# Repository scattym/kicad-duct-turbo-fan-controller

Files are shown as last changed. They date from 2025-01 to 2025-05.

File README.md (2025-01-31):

# kicad-duct-turbo-fan-controller
Wifi enabled fan controller projects for the duct turbo (ducturbo), terrabloom and ac infinity fans

Simple project marrying up 3 premade boards, the esp32 doit v2, a buck-boost board and a scd41 board.

Connects to the ducturbo 3.5mm to PWM control the fan speed.

Low side mosfet PWM chosen so that removal (or potentially failure) of the esp32 keeps the fan off.

Board will also work with the AC Infinity fans however there seems to be in internal 10k resistor on these fans, so changing R5 from 10K to 1K is needed to get the "off" voltage down to under 1 volt. With the following pins:

GND → GND

10V → VBUS

PWM → D+

TACH → D-

duct-turbo-fan-controller - original based of esp32 doit it board - done - tested

duct-turbo-fan-controller-v2 - moved to esp32-c3-wroom-02 - done - waiting testing

duct-turbo-fan-controller-v3 - add bme680 on board allow usb to power esp for programming - done - untested

duct-turbo-fan-controller-v4 - on board buck converter and on board scd41 - done - waiting testing

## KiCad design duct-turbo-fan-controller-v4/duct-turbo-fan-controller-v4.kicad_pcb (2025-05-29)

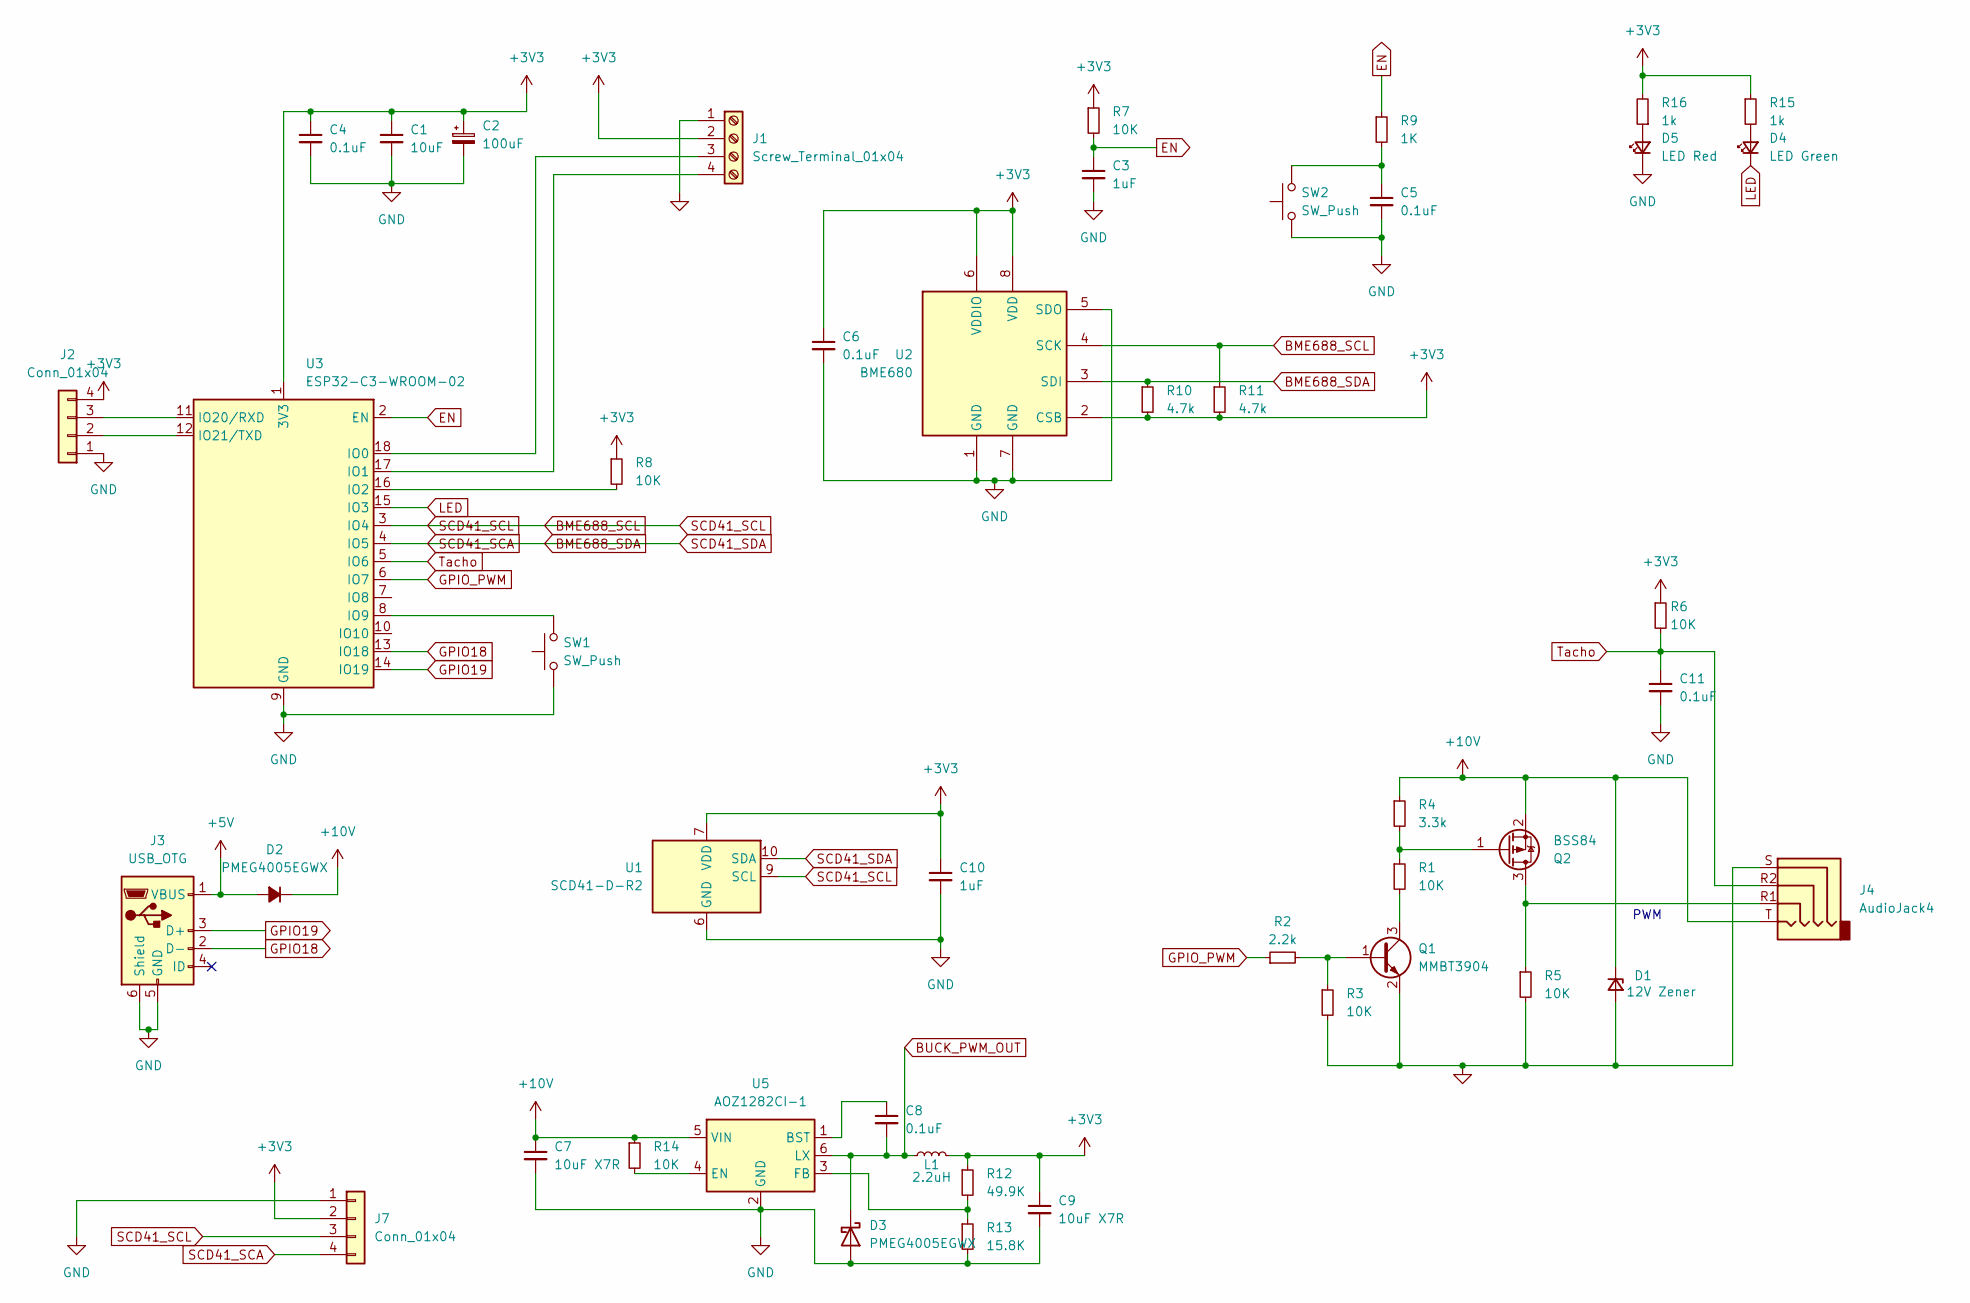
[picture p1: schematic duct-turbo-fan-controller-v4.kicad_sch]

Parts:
C1: 10uF; C_0805_2012Metric_Pad1.18x1.45mm_HandSolder
C2: 100uF; CP_EIA-3528-12_Kemet-T_Pad1.50x2.35mm_HandSolder
C3, C10: 1uF; C_0805_2012Metric_Pad1.18x1.45mm_HandSolder
C4, C5, C8: 0.1uF; C_0805_2012Metric_Pad1.18x1.45mm_HandSolder
C6, C11: 0.1uF; C_0603_1608Metric_Pad1.08x0.95mm_HandSolder
C7, C9: 10uF X7R; C_0805_2012Metric_Pad1.18x1.45mm_HandSolder
D1: 12V Zener; D_0805_2012Metric_Pad1.15x1.40mm_HandSolder
D2, D3: PMEG4005EGWX; D_SOD-123
D4: LED Green; LED_0603_1608Metric_Pad1.05x0.95mm_HandSolder
D5: LED Red; LED_0603_1608Metric_Pad1.05x0.95mm_HandSolder
J1: Screw_Terminal_01x04; TerminalBlock_Phoenix_MPT-0,5-4-2.54_1x04_P2.54mm_Horizontal
J2, J7: Conn_01x04; PinHeader_1x04_P2.54mm_Vertical
J3: USB_OTG; USB_Micro-B_Molex-105017-0001
J4: AudioJack4; Jack_3.5mm_KoreanHropartsElec_PJ-320D-4A_Horizontal
L1: 2.2uH; L_Bourns-SRN4018
Q1: MMBT3904; SOT-23
Q2: BSS84; SOT-23
R1, R3, R5, R7, R14: 10K; R_0805_2012Metric_Pad1.20x1.40mm_HandSolder
R2: 2.2k; R_0805_2012Metric_Pad1.20x1.40mm_HandSolder
R4: 3.3k; R_0805_2012Metric_Pad1.20x1.40mm_HandSolder
R6, R8: 10K; R_0603_1608Metric_Pad0.98x0.95mm_HandSolder
R9: 1K; R_0805_2012Metric_Pad1.20x1.40mm_HandSolder
R10, R11: 4.7k; R_0603_1608Metric_Pad0.98x0.95mm_HandSolder
R12: 49.9K; R_0805_2012Metric_Pad1.20x1.40mm_HandSolder
R13: 15.8K; R_0805_2012Metric_Pad1.20x1.40mm_HandSolder
R15, R16: 1k; R_0603_1608Metric_Pad0.98x0.95mm_HandSolder
SW1, SW2: SW_Push; SW_SPST_CK_RS282G05A3
U1: SCD41-D-R2; Sensirion_SCD4x-1EP_10.1x10.1mm_P1.25mm_EP4.8x4.8mm
U2: BME680; Bosch_LGA-8_3x3mm_P0.8mm_ClockwisePinNumbering
U3: ESP32-C3-WROOM-02
U5: AOZ1282CI-1; SOT-23-6

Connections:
+3V3: C1.1, C2.1, C4.1, C6.1, C9.1, C10.1, J1.2, J2.4, J7.2, L1.2, R6.1, R7.1, R8.1, R10.2, R11.2, R12.1, R15.1, R16.2, U1.7 (VDD), U1.19 (VDD), U2.2 (CSB), U2.6 (VDDIO), U2.8 (VDD), U3.1 (3V3)
+5V: D2.2 (A), J3.1 (VBUS)
+10V: C7.1, D1.1 (K), D2.1 (K), J4.T, Q2.2 (S), R4.1, R14.1, U5.5 (VIN)
BME688_SCL: J7.3, R11.1, U1.9 (SCL), U2.4 (SCK), U3.3 (IO4)
BME688_SDA: J7.4, R10.1, U1.10 (SDA), U2.3 (SDI), U3.4 (IO5)
BUCK_PWM_OUT: C8.2, D3.1 (K), L1.1, U5.6 (LX)
EN: C3.1, R7.2, R9.1, U3.2 (EN)
GND: C1.2, C2.2, C3.2, C4.2, C5.2, C6.2, C7.2, C9.2, C10.2, C11.2, D1.2 (A), D3.2 (A), D5.1 (K), J1.1, J2.1, J3.5 (GND), J3.6 (Shield), J4.S, J7.1, Q1.2 (E), R3.2, R5.2, R13.2, SW1.1, SW2.1, U1.6 (GND), U1.20 (GND), U1.21 (GND), U2.1 (GND), U2.5 (SDO), U2.7 (GND), U3.9 (GND), U3.19 (GND), U5.2 (GND)
GPIO18: J3.2 (D-), U3.13 (IO18)
GPIO19: J3.3 (D+), U3.14 (IO19)
GPIO_PWM: R2.1, U3.6 (IO7)
LED: D4.1 (K), U3.15 (IO3)
unnamed: C5.1, R9.2, SW2.2
unnamed: D4.2 (A), R15.2
unnamed: D5.2 (A), R16.1
unnamed: J1.3, U3.18 (IO0)
unnamed: J1.4, U3.17 (IO1)
unnamed: J2.2, U3.12 (IO21/TXD)
unnamed: J2.3, U3.11 (IO20/RXD)
unnamed: Q1.1 (B), R2.2, R3.1
unnamed: Q1.3 (C), R1.2
unnamed: J4.R1, Q2.3 (D), R5.1
unnamed: Q2.1 (G), R1.1, R4.2
unnamed: R8.2, U3.16 (IO2)
unnamed: SW1.2, U3.8 (IO9)
unnamed: C8.1, U5.1 (BST)
unnamed: R14.2, U5.4 (EN)
unnamed: R12.2, R13.1, U5.3 (FB)
Tacho: C11.1, J4.R2, R6.2, U3.5 (IO6)

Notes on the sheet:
PWM

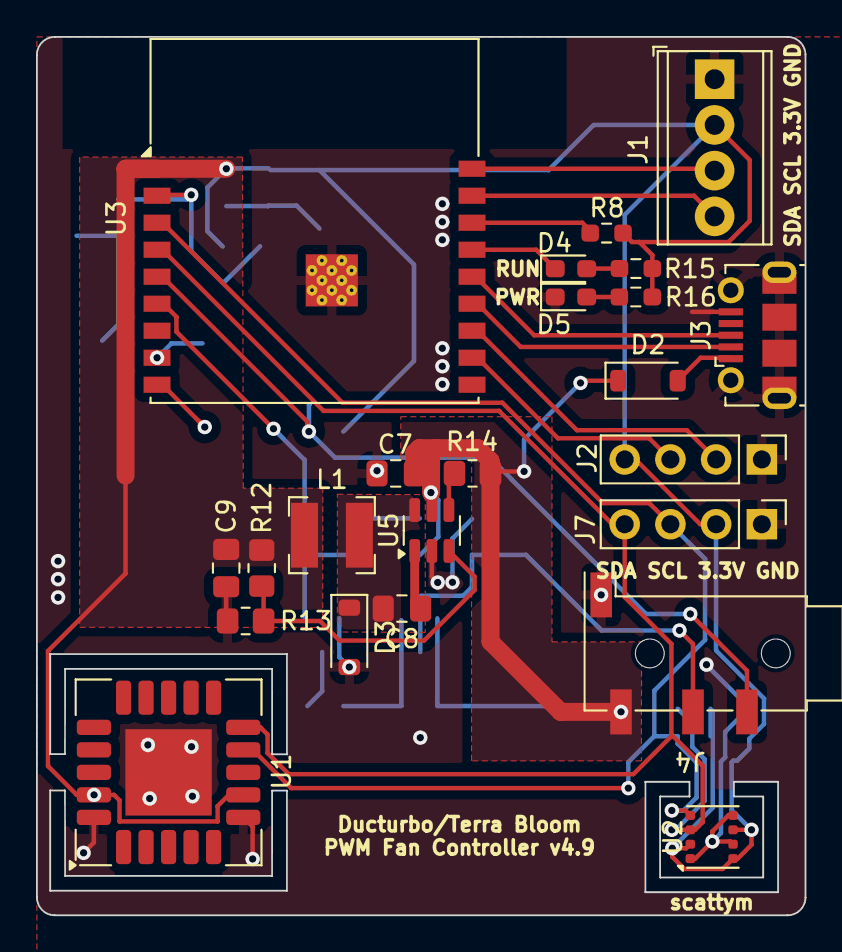
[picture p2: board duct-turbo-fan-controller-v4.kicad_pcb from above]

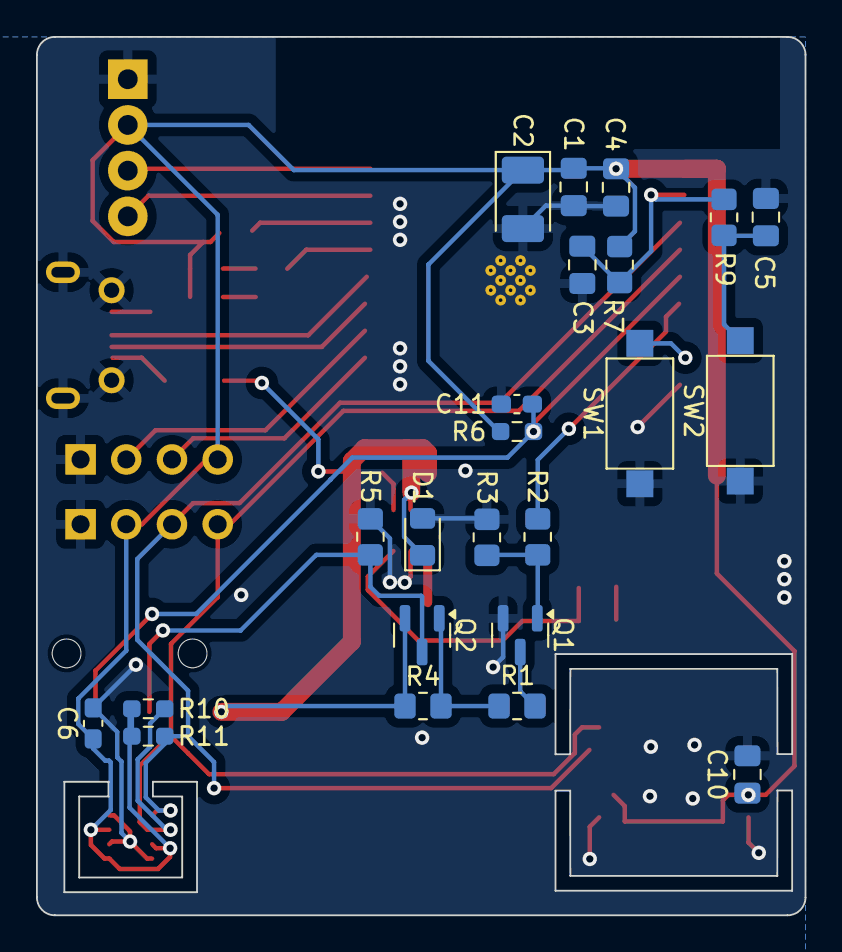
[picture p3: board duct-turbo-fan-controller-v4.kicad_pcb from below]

Board: 2 copper layers, 42.7 x 48.8 mm, 46 parts (23 on the bottom side), 29 nets.

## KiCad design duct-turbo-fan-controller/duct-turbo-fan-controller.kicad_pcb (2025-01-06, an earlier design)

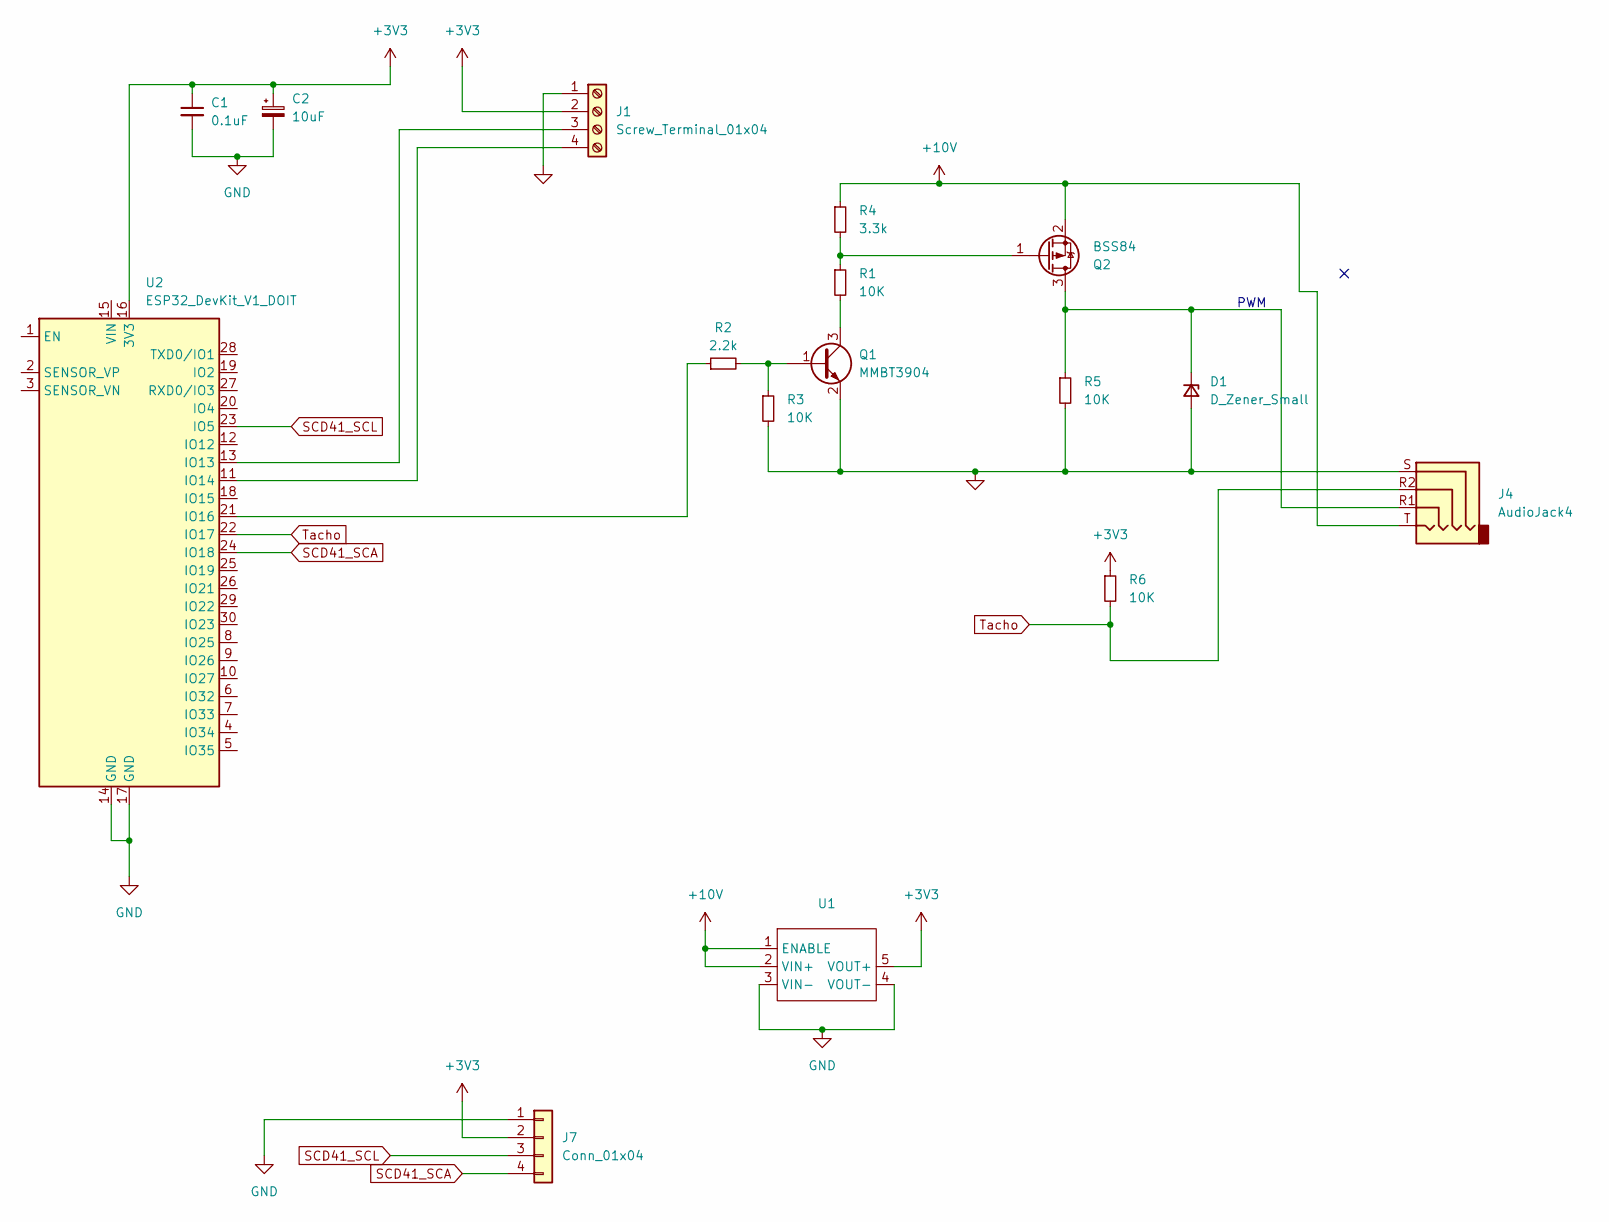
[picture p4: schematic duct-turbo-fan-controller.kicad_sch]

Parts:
C1: 0.1uF; C_0805_2012Metric_Pad1.18x1.45mm_HandSolder
C2: 10uF; CP_EIA-3528-12_Kemet-T_Pad1.50x2.35mm_HandSolder
D1: D_Zener_Small; D_0805_2012Metric_Pad1.15x1.40mm_HandSolder
J1: Screw_Terminal_01x04; TerminalBlock_Phoenix_MPT-0,5-4-2.54_1x04_P2.54mm_Horizontal
J4: AudioJack4; Jack_3.5mm_KoreanHropartsElec_PJ-320D-4A_Horizontal
J7: Conn_01x04; PinHeader_1x04_P2.54mm_Vertical
Q1: MMBT3904; SOT-23
Q2: BSS84; SOT-23
R1, R3, R5, R6: 10K; R_0805_2012Metric_Pad1.20x1.40mm_HandSolder
R2: 2.2k; R_0805_2012Metric_Pad1.20x1.40mm_HandSolder
R4: 3.3k; R_0805_2012Metric_Pad1.20x1.40mm_HandSolder
U1: Buck-Boost-Converter-Board-3.3V
U2: ESP32_DevKit_V1_DOIT; esp32_devkit_v1_doit

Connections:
+3V3: C1.1, C2.1, J1.2, J7.2, R6.1, U1.5 (VOUT+), U2.16 (3V3)
+10V: J4.T, Q2.2 (S), R4.1, U1.1 (ENABLE), U1.2 (VIN+)
GND: C1.2, C2.2, D1.2 (A), J1.1, J4.S, J7.1, Q1.2 (E), R3.2, R5.2, U1.3 (VIN-), U1.4 (VOUT-), U2.14 (GND), U2.17 (GND)
unnamed: D1.1 (K), J4.R1, Q2.3 (D), R5.1
unnamed: J1.3, U2.13 (IO13)
unnamed: J1.4, U2.11 (IO14)
unnamed: Q1.1 (B), R2.2, R3.1
unnamed: Q1.3 (C), R1.2
unnamed: Q2.1 (G), R1.1, R4.2
unnamed: R2.1, U2.21 (IO16)
SCD41_SCA: J7.4, U2.24 (IO18)
SCD41_SCL: J7.3, U2.23 (IO5)
Tacho: J4.R2, R6.2, U2.22 (IO17)

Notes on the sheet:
PWM

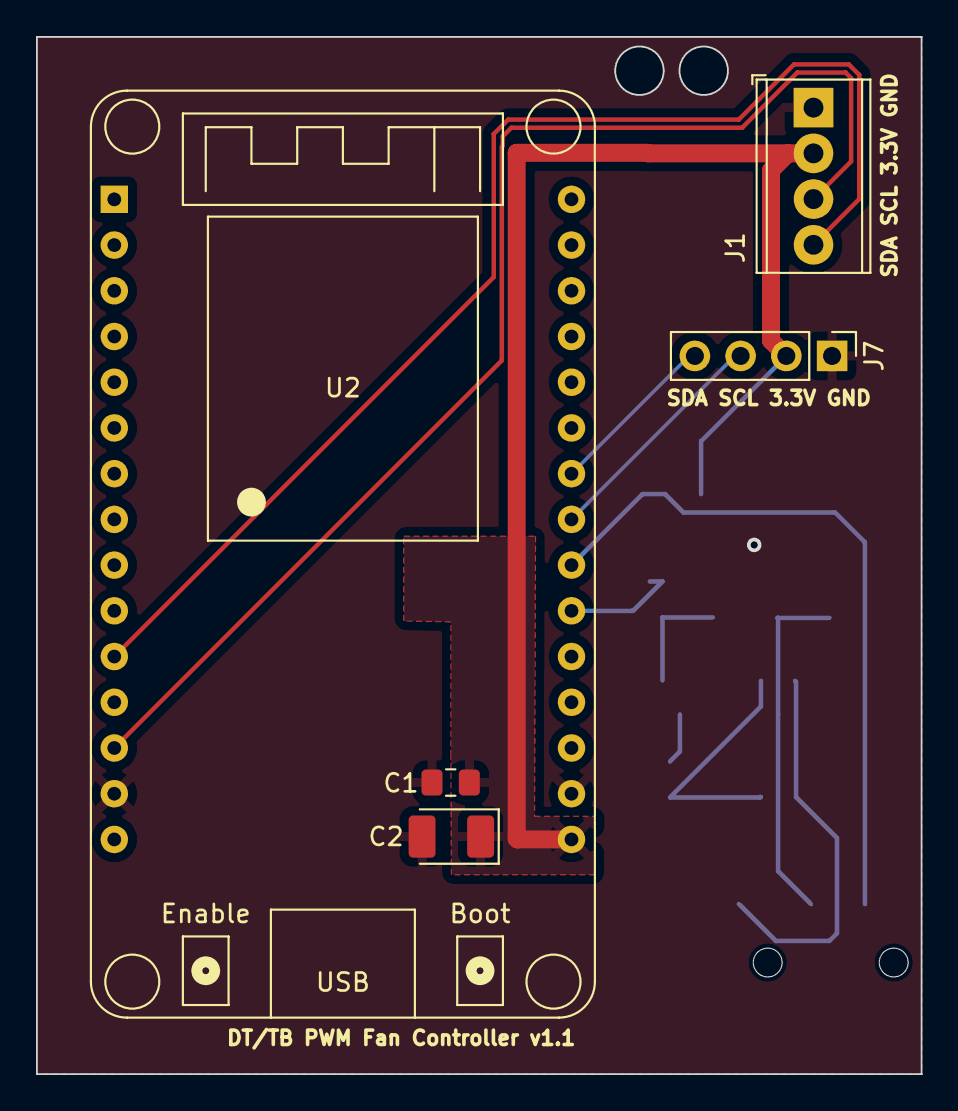
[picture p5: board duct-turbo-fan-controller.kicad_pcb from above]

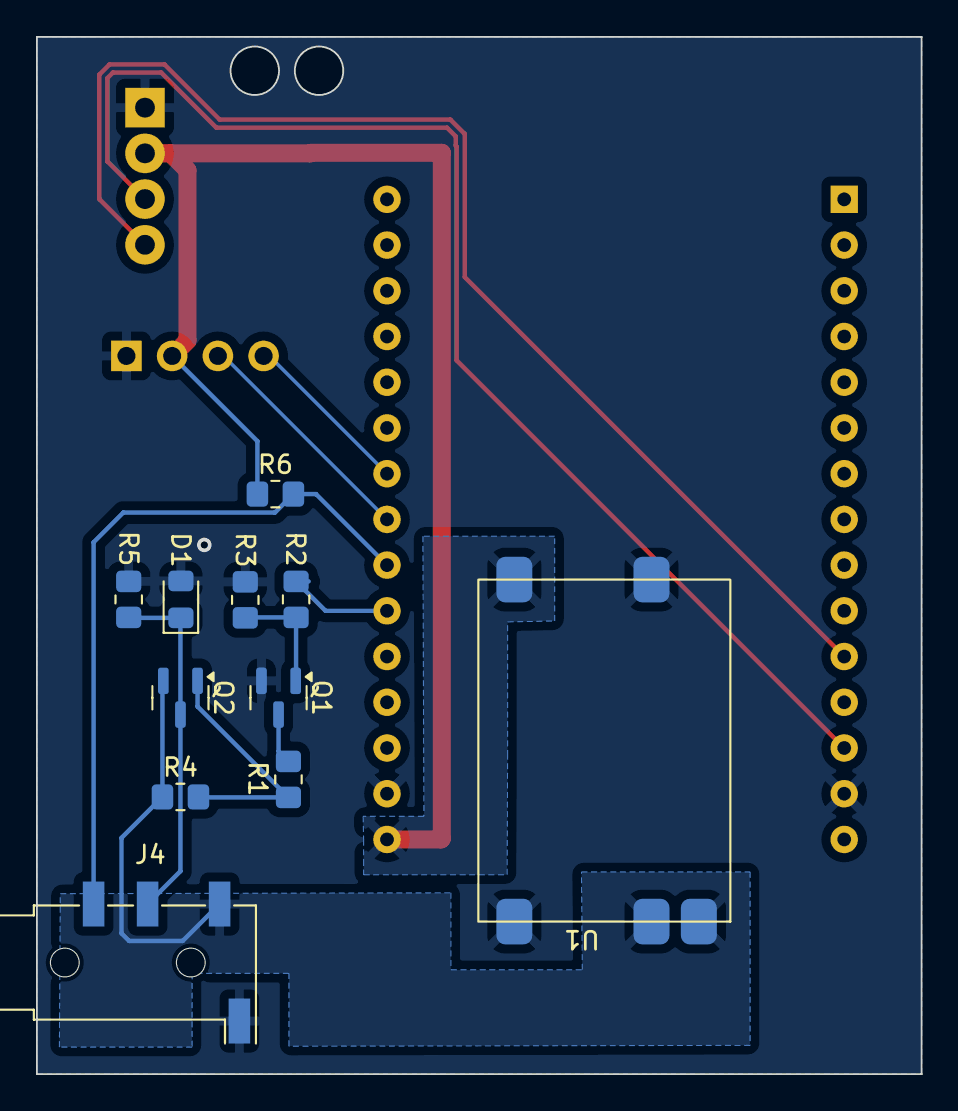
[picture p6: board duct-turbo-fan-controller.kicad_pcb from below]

Board: 2 copper layers, 49.1 x 57.6 mm, 16 parts (11 on the bottom side), 13 nets.

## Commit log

2025-01-06 Import of duct turbo fan controller
    [duct-turbo-fan-controller-B_Cu.gbl, duct-turbo-fan-controller-B_Mask.gbs, duct-turbo-fan-controller-B_Paste.gbp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]
2025-01-06 Add new export file
    [duct-turbo-fan-controller.kicad_pcb]
2025-01-06 Remove old esp32 pwm references.
2025-01-06 Add v2 board with embedded esp32 c3 chip
    [duct-turbo-fan-controller-v2-B_Cu.gbl, duct-turbo-fan-controller-v2-B_Mask.gbs, duct-turbo-fan-controller-v2-B_Paste.gbp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]
2025-01-07 Move 3.5mm jack and reduce board size. Fix GND of USB_OTG.
    [duct-turbo-fan-controller-v2.kicad_pcb]
2025-01-07 Move 3.3v line away from grounding thermal pad.
    [duct-turbo-fan-controller-v2.kicad_pcb]
2025-01-07 Update version number.
    [duct-turbo-fan-controller-v2.kicad_pcb]
2025-01-07 Add GND via on input from 3.5mm jack
    [duct-turbo-fan-controller-v2.kicad_pcb]
2025-01-07 Add gnd via as esp32 thermal pad will not be soldered.
    [duct-turbo-fan-controller-v2.kicad_pcb]
2025-01-07 Bump board version
    [duct-turbo-fan-controller-v2.kicad_pcb]
2025-01-14 Start working on v3 with bme68X
    [duct-turbo-fan-controller-v3-B_Cu.gbl, duct-turbo-fan-controller-v3-B_Mask.gbs, duct-turbo-fan-controller-v3-B_Paste.gbp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]
2025-01-15 Connecting up the bme680/688 in pcb layout
    [duct-turbo-fan-controller-v3.kicad_pcb]
2025-01-15 Update track location to get more real estate for buck converter
    [duct-turbo-fan-controller-v3.kicad_pcb]
2025-01-16 Fix missing ground on bme68x
    [duct-turbo-fan-controller-v3.kicad_pcb]
2025-01-16 Add diode from usb 5v to power in.
    [duct-turbo-fan-controller-v3.kicad_pcb, duct-turbo-fan-controller-v3.kicad_sch]
2025-01-16 Bump version for next release
    [duct-turbo-fan-controller-v3.kicad_pcb]
2025-01-16 New design with on-board buck converter
    [duct-turbo-fan-controller-v4-B_Cu.gbl, duct-turbo-fan-controller-v4-B_Mask.gbs, duct-turbo-fan-controller-v4-B_Paste.gbp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]
2025-01-17 Move to smaller inductor as buck switch is 1MHz
    [duct-turbo-fan-controller-v4.kicad_pcb, duct-turbo-fan-controller-v4.kicad_sch]
2025-01-17 Round the edges of the board
    [duct-turbo-fan-controller-v4.kicad_pcb]
2025-01-17 Add label for pull up. Add tag.
    [duct-turbo-fan-controller-v4.kicad_pcb, duct-turbo-fan-controller-v4.kicad_sch]
2025-01-19 Add scd41 to the board.
    [duct-turbo-fan-controller-v4.kicad_pcb, duct-turbo-fan-controller-v4.kicad_sch]
2025-01-19 Shorter route for the 3.3v line to scd41
    [duct-turbo-fan-controller-v4.kicad_pcb]
2025-01-19 New tag for the v4 board
    [duct-turbo-fan-controller-v4.kicad_pcb]
2025-01-19 A couple of minor routing changes
    [duct-turbo-fan-controller-v4.kicad_pcb]
2025-01-20 Add missing GND connection for SCD41
    Add example esphome home configurations for each board. Not complete.
    [duct-turbo-fan-controller-v4.kicad_pcb, ventilation-controller-v1.yaml, ventilation-controller-v2.yaml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]
2025-01-20 Increase size of 3.3v net to esp32
    [duct-turbo-fan-controller-v4.kicad_pcb]
2025-01-20 New tag for v4 board
    [duct-turbo-fan-controller-v4.kicad_pcb]
2025-01-22 Increase size of cutouts to 0.8mm as per pcbway spec.
    [duct-turbo-fan-controller-v4.kicad_pcb]
2025-01-22 Move ground via to be fully enclosed
    [duct-turbo-fan-controller-v4.kicad_pcb]
2025-01-22 Increase size of the track from 10V in to Buck converter
    [duct-turbo-fan-controller-v4.kicad_pcb]
2025-01-23 Add capacitance close to sc41 for ripple reduction.
    [duct-turbo-fan-controller-v4.kicad_pcb, duct-turbo-fan-controller-v4.kicad_sch]
2025-01-23 Bump board version to 4.5
    [duct-turbo-fan-controller-v4.kicad_pcb]
2025-01-23 Move capacitance closer to scd41
    [duct-turbo-fan-controller-v4.kicad_pcb]
2025-01-23 Add missing schottky diode on the pwm output
    [duct-turbo-fan-controller-v4.kicad_pcb, duct-turbo-fan-controller-v4.kicad_sch]
2025-01-23 Extra GND vias to help dissipate buck converter thermals
    [duct-turbo-fan-controller-v4.kicad_pcb]
2025-01-28 Updates to the labels on diodes and inductors
    [duct-turbo-fan-controller-v4.kicad_sch]
2025-01-31 Add LEDs to PCB to help identify state.
    [duct-turbo-fan-controller-v4.kicad_pcb, duct-turbo-fan-controller-v4.kicad_sch]
2025-02-02 Reduce size of R8 to 0603. Improve labels of LEDs.
    [duct-turbo-fan-controller-v4.kicad_pcb, duct-turbo-fan-controller-v4.kicad_sch]
2025-02-02 Update version number ready for tagging
    [duct-turbo-fan-controller-v4.kicad_pcb]
2025-02-05 Add values to led resistors. Redraw zone fills.
    [duct-turbo-fan-controller-v4.kicad_pcb, duct-turbo-fan-controller-v4.kicad_sch]
2025-02-07 Fix a couple of schematic errors.
    1. External PWM was tied to ground.
    2. BME688 SCA and SCL pins were tied together.
    [duct-turbo-fan-controller-v4.kicad_pcb, duct-turbo-fan-controller-v4.kicad_sch]
2025-02-07 Bump board version.
    [duct-turbo-fan-controller-v4.kicad_pcb]
2025-02-07 Fill redraw
    [duct-turbo-fan-controller-v4.kicad_pcb]
2025-02-07 Add symbols for the smd usbc.
    May need to find different devices as reported that
    the pins are only vbus and gnd with no data pins.
2025-02-07 Add gnd tracks where fill zone incomplete.
    Update leds in schematic to be more readable.
    [duct-turbo-fan-controller-v4.kicad_pcb, duct-turbo-fan-controller-v4.kicad_sch]
2025-02-14 Updates to board
    [duct-turbo-fan-controller-v4.kicad_sch]
2025-02-14 Fix footprint for buck diode in schematic.
    Add values for buck capacitors in schematic.
    [duct-turbo-fan-controller-v4.kicad_sch]
2025-02-14 Fix buck diode footprint in pcb
    [duct-turbo-fan-controller-v4.kicad_sch]
2025-02-14 Fix buck diode footprint on pcb
    [duct-turbo-fan-controller-v4.kicad_pcb]
2025-02-18 Add input resistor from Tacho pin
    [duct-turbo-fan-controller-v4.kicad_pcb, duct-turbo-fan-controller-v4.kicad_sch]
2025-03-08 Fix bme688 wiring by adding +3.3V to CSB pin.
    Was defaulting to spi mode and taking out the whole i2c link
    [duct-turbo-fan-controller-v4.kicad_pcb, duct-turbo-fan-controller-v4.kicad_sch]
2025-03-09 Fix labelling of the power and run leds.
    They were the wrong way around.
    [duct-turbo-fan-controller-v4.kicad_pcb]
2025-05-26 Add filter capacitor to input tacho pin.
    [duct-turbo-fan-controller-v4.kicad_pcb, duct-turbo-fan-controller-v4.kicad_sch]
2025-05-26 Bump board version to v4.9
    [duct-turbo-fan-controller-v4.kicad_pcb]
2025-05-29 Reduce size of scd41 cap to 0805
    [duct-turbo-fan-controller-v4.kicad_pcb, duct-turbo-fan-controller-v4.kicad_sch]
2025-11-09 Clean up to avoid overlapping wires.
    [duct-turbo-fan-controller-v4.kicad_sch]
